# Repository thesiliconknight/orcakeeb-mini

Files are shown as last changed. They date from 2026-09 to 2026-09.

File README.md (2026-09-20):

# orcakeeb-mini

A 16-key mechanical macropad with a rotary encoder, individual RGB, and a 0.91 inch OLED screen. The board is built around the Waveshare (or clone)  RP2040-Zero devboard, which handles the data and power. Fully compatible with QMK and KMK (CircuitPython) firmware.(Ive used KMK)

## Pictures

| Top View | Bottom View |
| :---: | :---: |
| Board Front | Board Back |

## Features

* **Main Controller:** Waveshare RP2040-Zero Devboard (clones are also ok)
* **Switch Matrix:** 3x4 + 1x3 grid supporting 15 cherry-mx (or compatible) mechanical switches,with individual diodes to prevent ghosting.
* **RGB Leds:** 16 reverse-mounted SK6812MINI-E LEDs inside the switch cutouts.
* **Rotary Encoder:** Standard rotary encoder with push-button functionality. 
* **OLED Display:** I2C header for a 0.91 inch OLED module to display modes or custom graphics.

## Components Used

* **Microcontroller:** Waveshare RP2040-Zero Dev-Board
* **Switches:** 15x Cherry MX Switches or similar knock-offs
* **Diodes:** 15x 1N4148 
* **LEDs:** 15x SK6812MINI-E
* **Screen:** 0.91 inch I2C OLED Module
* **Miscellaneous:** 1x 10µF Ceramic Cap , 16x 0.1µF Caps, EC11 (or similar knockoffs) Rotary Encoder

## Bill of Materials (BOM)

| Qty | Component | Designators | Unit Price (in INR) | Total Cost (also INR) | Source/Links |
| :---: | :--- | :--- | :---: | :---: | :--- |
| 1 | RP2040-Zero Dev-Board | U1 | 250.00 | 250.00 | [Robu.in](https://robu.in/product/rp2040-zero-for-raspberry-pi-microcontroller-with-soldering/) |
| 1 | 0.91" I2C OLED  | U2 | 212.00 | 212.00 | [Robu.in](https://robu.in/product/blue-oled-display-module/) |
| 1 | EC11 Encoder | SW19 | 47.00 | 47.00 | [Robu.in](https://robu.in/product/m274-360-degree-rotary-encoder-module-brick-sensor/) |
| 15 | SK6812MINI-E RGB LED | D1-D3, D5-D16 | 8.60 | 155.00 | [ETStore](https://www.etstore.in/products/e9974) |
| 15 | Mechanical Switches | SW1-SW12, SW14-SW16 | 18.00 | 360.00 | [StacksKB](https://stackskb.com/store/click-inc-hp-switch-pack-of-10-pre-order/) |
| 1 | Numpad Keycap Set | - | 100.00 | 100.00 | [StacksKB](https://stackskb.com/store/numpad-keycaps/?attribute_variant=Black+Gradient) |
| 15 | 1N4148W Diode | D17-D28, D30-D32 | 0.70 | 14.00 | [Robu.in](https://robu.in/product/1n4148w-sod-123-1206-diodereel-of-3000/) |
| 2 | 10kΩ Resistor  | R3, R4 | 0.86 | 10.00 | [Robu.in](https://robu.in/product/10k-ohm-1-4w-0603-surface-mount-chip-resistor-pack-of-100/) |
| 1 | 10µF Capacitor  | C17 | 1.54 | 10.64 | [Robu.in](https://robu.in/product/tcc0603x5r106k160ct-cctc-smt-ceramic-capacitors-0603-x5r-106k10%c2%b5f%c2%b110-rated-voltage16v-thickness0-80mm-tape/) |
| 1 | 10nF Capacitor  | C22 | 0.50 | 10.29 | [Robu.in](https://robu.in/product/tcc0603x7r103k500cts-cctc-smt-ceramic-capacitors-0603-x7r-103k10nf%c2%b110-rated-voltage50v-thickness0-80mm-tape/) |
| 15 | 100nF Capacitor | C1-C3, C5-C16 | 0.00 | 0.00 | [Robu.in](https://robu.in/product/100nf-0603-surface-mount-multilayer-ceramic-capacitor-pack-of-40/) |
| 5 | Custom PCB | - | 405.00 | 2025.00 | no link see folder |
| | | | **Total:** | **₹3,193.93** (33.29) | |

| Schematic Design |
| :---: |
| Schematic Diagram |

| PCB Top Layer Routing | PCB Bottom Layer Routing |
| :---: | :---: |
| Top Routing | Bottom Routing |

### Connections
* **VBUS (5V):** Routes power straight from the USB-C port to the main 10µF bulk capacitor, then daisy-chains to the VDD pins of all 16 LEDs. 
* **OLED Header:** Connecetd to pins (SDA) G10 (SCK) G9
* **Encoder:** Connected to Pin G4, and A And B pins to G3 and G2
* **RGB Led Data:** Data IN pins connected to G14
  
## License

This hardware project is open-source and licensed under the CERN Open Hardware Licence Version 2 - Strongly Reciprocal (CERN-OHL-S-2.0). 

You are free to copy, modify, distribute, and manufacture this board for personal or commercial use. However, if you modify these schematic or layout files and distribute your new design, you must release those modifications under this exact same CERN-OHL-S-2.0 license.

This design is shared without any warranty or implied guarantee. Check the LICENSE file for the full legal text.

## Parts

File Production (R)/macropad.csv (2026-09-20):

Id | Designator | Footprint | Quantity | Designation | Supplier and ref
1 | C1, C2, C3, C5, C6, C7, C8, C9, C10, C11, C12, C13, C14, C15, C16 | C_0603_1608Metric | 15 | 100nf
2 | C17 | C_0603_1608Metric | 1 | 10uf
3 | C22 | C_0603_1608Metric | 1 | 10nF
4 | D1, D2, D3, D5, D6, D7, D8, D9, D10, D11, D12, D13, D14, D15, D16 | LED_SK6812MINI-E_3.2x2.8mm_P1.5mm_ReverseMount | 15 | SK6812MINI-E
5 | D17, D18, D19, D20, D21, D22, D23, D24, D25, D26, D27, D28, D30, D31, D32 | D_SOD-123 | 15 | 1N4148W
6 | R3, R4 | R_0603_1608Metric | 2 | 10k
7 | SW1, SW2, SW3, SW4, SW5, SW6, SW7, SW8, SW9, SW10, SW11, SW12, SW14, SW15, SW16 | SW_Cherry_MX_1.00u_PCB | 15 | SW_Push
8 | SW19 | RotaryEncoder_Alps_EC11E-Switch_Vertical_H20mm | 1 | RotaryEncoder_Switch
9 | U1 | RP2040 MINI | 1 | RP2040_MICRO
10 | U2 | Untitled | 1 | 0.91_OLED

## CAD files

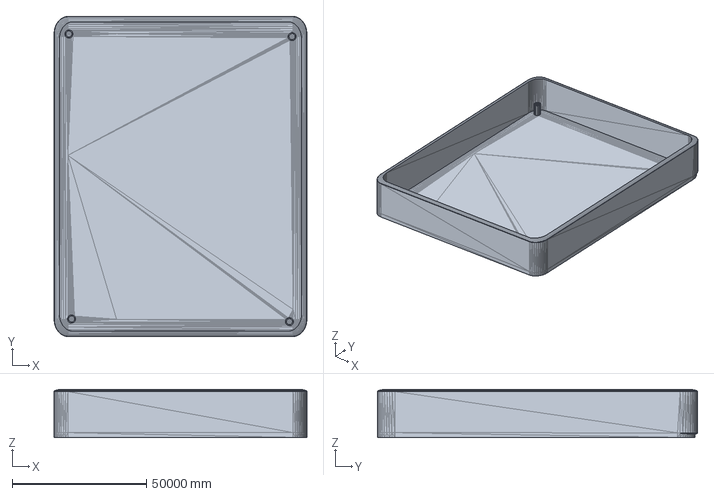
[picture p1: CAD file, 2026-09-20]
Case/macropadcase.stp
94000.0 x 119000.0 x 18000.4 mm

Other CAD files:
Case/macropadcase.stl

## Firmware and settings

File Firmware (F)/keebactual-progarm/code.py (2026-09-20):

print("Waking up the keeb...")

import board
import busio
import sys

from kmk.kmk_keyboard import KMKKeyboard
from kmk.keys import KC
from kmk.scanners import DiodeOrientation
from kmk.modules.encoder import EncoderHandler
from kmk.extensions.RGB import RGB
from kmk.extensions.display import Display, TextEntry
from kmk.extensions.display.ssd1306 import SSD1306

orcakeeb_hw = KMKKeyboard()

# rp2040 gpio matrix pins
orcakeeb_hw.col_pins = (board.GP28, board.GP27, board.GP26, board.GP1)
orcakeeb_hw.row_pins = (board.GP5, board.GP6, board.GP7, board.GP8)
orcakeeb_hw.diode_orientation = DiodeOrientation.COL2ROW

# encoder logic
media_encoder_sys = EncoderHandler()
media_encoder_sys.pins = ((board.GP3, board.GP2, board.GP4, False),)
media_encoder_sys.map = [ ((KC.VOLD, KC.VOLU, KC.MUTE),) ]
orcakeeb_hw.modules.append(media_encoder_sys)

# rgb logic (all 16 of em)
sk6812_matrix_leds = RGB(pixel_pin=board.GP14, num_pixels=16, val_limit=100, val_default=20)
orcakeeb_hw.extensions.append(sk6812_matrix_leds)

try:
    i2c0_bus = busio.I2C(board.GP9, board.GP10)
    oled_driver_ic = SSD1306(i2c=i2c0_bus, device_address=0x3C)
    
    status_display_ui = Display(
        display=oled_driver_ic,
        entries=[
            TextEntry(text="ORCAKEEB", x=0, y=0, y_anchor="T"),
            TextEntry(text="NUMPAD", x=0, y=10, y_anchor="T"),
        ],
        width=128, height=32
    )
    orcakeeb_hw.extensions.append(status_display_ui)
    
except ValueError as pin_err:
    print("Hardware Error: I2C pins in use or missing pull-ups ->", pin_err)
except RuntimeError as i2c_err:
    print("Hardware Error: SSD1306 not detected at address 0x3C ->", i2c_err)
except Exception as e:
    print("bro i think you forogot the oled")
    print("oopse woopsie smthin wrong", e)
    if hasattr(sys, 'print_exception'):
        sys.print_exception(e)

# numpad mapping?
orcakeeb_hw.keymap = [
    [
        KC.KP_7, KC.KP_8,   KC.KP_9,     KC.KP_SLASH,
        KC.KP_4, KC.KP_5,   KC.KP_6,     KC.KP_ASTERISK,
        KC.KP_1, KC.KP_2,   KC.KP_3,     KC.KP_MINUS,
        KC.KP_0, KC.KP_DOT, KC.KP_ENTER, KC.KP_PLUS,
    ]
]

if __name__ == '__main__':
    orcakeeb_hw.go()

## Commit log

2026-09-14 Added the case
    [macropadcase.stl]
2026-09-20 bom updated w/ links
2026-09-20 Revise README for clarity and component updates
    Updated the README to clarify specifications and component details, including changes to the switch matrix and quantities of components used.
2026-09-20 Update macropad.csv to new format with headers
    [macropad.csv]
2026-09-20 added stp file
    [macropadcase.stp]
2026-09-20 added assembly files
